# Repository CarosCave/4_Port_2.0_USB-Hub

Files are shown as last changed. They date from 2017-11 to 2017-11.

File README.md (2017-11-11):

# 4_Port_2.0_USB-Hub
I made a 4 port 2.0 USB-Hub with an exar XR22404 Chip. I wanted to test the schematic for the USB-Chip to use it in a further project. Version 1 is up and running here. But the costs for one complete equipped PCB is about 60€. Now in V2.0 I decreased the costs to 28€ for the parts.

You will find the:
-  CAD-Files in the folder **KiCAD**
-  The manufacturing files in the folder **Gerber-files**
-  The PDF documents in the folder **PDF**
-  The licence files from CERN OHL v. 1.2 under **Licence**

Or you order the complete Project by my friends from Aisler B.V.. The will deliver the complete project incl. all parts (excl. the USB-Chip from Exar). You'll find the project under the following link:
https://aisler.net/DK1CMB/4-port-2-0-usb-hub/main-pcb

The USB-Chip is an Exar XR22404CG28TR-F.

## Licence:  
**Copyright Caroline Brix 2017.**  
This documentation describes Open Hardware and is licensed under the CERN OHL v. 1.2.
You may redistribute and modify this documentation under the terms of the CERN OHL v.1.2. (http://ohwr.org/cernohl). This documentation is distributed WITHOUT ANY EXPRESS OR IMPLIED WARRANTY, INCLUDING OF MERCHANTABILITY, SATISFACTORY QUALITY AND FITNESS FOR A PARTICULAR PURPOSE. Please see the CERN OHL v.1.2 for applicable conditions

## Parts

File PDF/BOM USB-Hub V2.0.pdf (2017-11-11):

ID | Bezeichner | Gehäuse | Stückzahl | Bezeichnung | Hersteller | Hersteller-Teilenummer | Mouser-Bestellnummer | Digikey-Bestellnummer | Preis Mouser | Preis Digikey
| Identifier | Case | Pieces | Description | Manufacturer | Manufacturer part number | Mouser part number | Digikey part number | Costs Mouser | Costs Digikey
1 | IC1 | SSOP-28 | 1 | USB-IC USB 2.0 4-Port Hub | Exar | XR22404CG28TR-F | 701-XR22404CG28TR-F | nA | 2,02 € | 2,02 € | | - €
2 | J1 | USB B | 1 | USB_B_WE | Wurth | 61400416121 | 710-61400416121 | 732-2108-ND | 1,20 € | 1,20 € | 1,20 € | 1,20 €
3 | J6,J7,J8,J9 | USB A | 4 | USB_A_shielded | Wurth | 614004160211 | 710-614004160211 | 732-8248-ND | 1,50 € | 6,00 € | 1,48 € | 5,92 €
4 | C1,C3,C5 | SMD 0805 | 3 | 100nF | Wurth | 885012207072 | 710-885012207072 | 732-8061-1-ND | 0,06 € | 0,18 € | 0,09 € | 0,27 €
5 | C2,C4 | SMD 0805 | 2 | 4,7µF | Vishay | VJ0805G475KXYTW1BC | 77-VJ0805G475KXYTBC | - | 0,09 € | 0,17 € | | - €
| | | | | Taiyo | TMK212BJ475KG-T | - | 587-1782-1-ND | | | 0,24 € | 0,48 €
6 | C6,C7,C8,C9,C10,C11,C12,C13 | SMD 0805 | 8 | 680nF | Kemet | C0805C684K4RACTU | 80-C0805C684K4R | 399-9267-1-ND | 0,17 € | 1,36 € | 0,17 € | 1,36 €
7 | F1 | SMD 1206 | 1 | Polyfuse | Eaton | PTS120615V050 | 504-PTS120615V050 | 283-3140-1-ND | 0,26 € | 0,26 € | 0,27 € | 0,27 €
8 | FL1,FL2,FL3,FL4,FL5 | 1206 | 5 | EMI Common Mode Filter | Wurth | 744232090 | 710-744232090 | 732-1469-1-ND | 1,12 € | 5,60 € | 1,12 € | 5,60 €
9 | L1,L2,L3,L4 | SMD 0805 | 4 | 600R@100MHz | Wurth | 74279204 | 710-74279204 | 732-1620-1-ND | 0,19 € | 0,76 € | 0,20 € | 0,80 €
10 | R1,R2,R10 | SMD 0805 | 3 | 2k7 | Vishay | CRCW08052K70JNEA | 71-CRCW08052K70JNEA | 541-2.7KACT-ND | 0,09 € | 0,26 € | 0,08 € | 0,24 €
11 | R3 | SMD 0805 | 1 | 470 | Panasonic | ERJ-U06F4700V | 667-ERJ-U06F4700V | - | 0,23 € | 0,23 € | | - €
| | | | | Bourns | CR0805-FX-4700ELF | - | CR0805-FX-4700ELFCT-ND | | | 0,08 € | 0,08 €
12 | R4 | SMD 0805 | 1 | 40k2 | Vishay | CRCW080540K2FKEA | 71-CRCW0805-40.2K-E3 | 541-40.2KCCT-ND | 0,09 € | 0,09 € | 0,08 € | 0,08 €
13 | R5,R8,R9 | SMD 0805 | 3 | 10k | Yageo | RC0805FR-0710KL | 603-RC0805FR-0710KL | 311-10.0KCRCT-ND | 0,09 € | 0,26 € | 0,08 € | 0,24 €
14 | R6 | SMD 0805 | 1 | 0 | Yageo | RC0805JR-070RL | 603-RC0805JR-070RL | 311-0.0ARCT-ND | 0,09 € | 0,09 € | 0,08 € | 0,08 €
15 | R7 | SMD 0805 | 1 | 100k | Yageo | RC0805FR-07100KL | 603-RC0805FR-07100KL | 311-100KCRCT-ND | 0,09 € | 0,09 € | 0,08 € | 0,08 €
16 | U1,U2,U3,U4,U5 | SOT-23-6L | 5 | WE-TVS Diode | Wurth | 82400102 | 710-82400102 | 732-4473-1-ND | 0,74 € | 3,70 € | 0,74 € | 3,70 €
17 | Y1 | SMD 3225 | 1 | 12MHz | Diodes Incorporated | FL1200135 | 729-FL1200135 | FL1200135 CT-ND | 0,72 € | 0,72 € | 0,59 € | 0,59 €
18 | D1,D2,D3,D4,D5 | SMD 0805 | 5 | LED | Kingbright | APT2012SGC | 604-APT2012SGC | 754-1131-1-ND | 0,07 € | 0,36 € | 0,33 € | 1,65 €
19 | Q1 | SOT-23 | 1 | MOSFET T1 60V PCH | ON Semiconductor | NVR5124PLT1G | 863-NVR5124PLT1G | - | 0,37 € | 0,37 € | | - €
| | | | MOSFET P-CH 60V 1.8A CPH3 | ON Semiconductor | CPH3351-TL-W | - | CPH3351-TL-WOSCT-ND | | - € | 0,41 € | - €
20 | J2,J3,J4,J5 | 3.2mm | 4 | Mounting Hole
| | | | | | | | | Netto | 23,69 € | | 22,64 €
| | | | | | | | | Brutto | 28,19 € | | 26,94 €

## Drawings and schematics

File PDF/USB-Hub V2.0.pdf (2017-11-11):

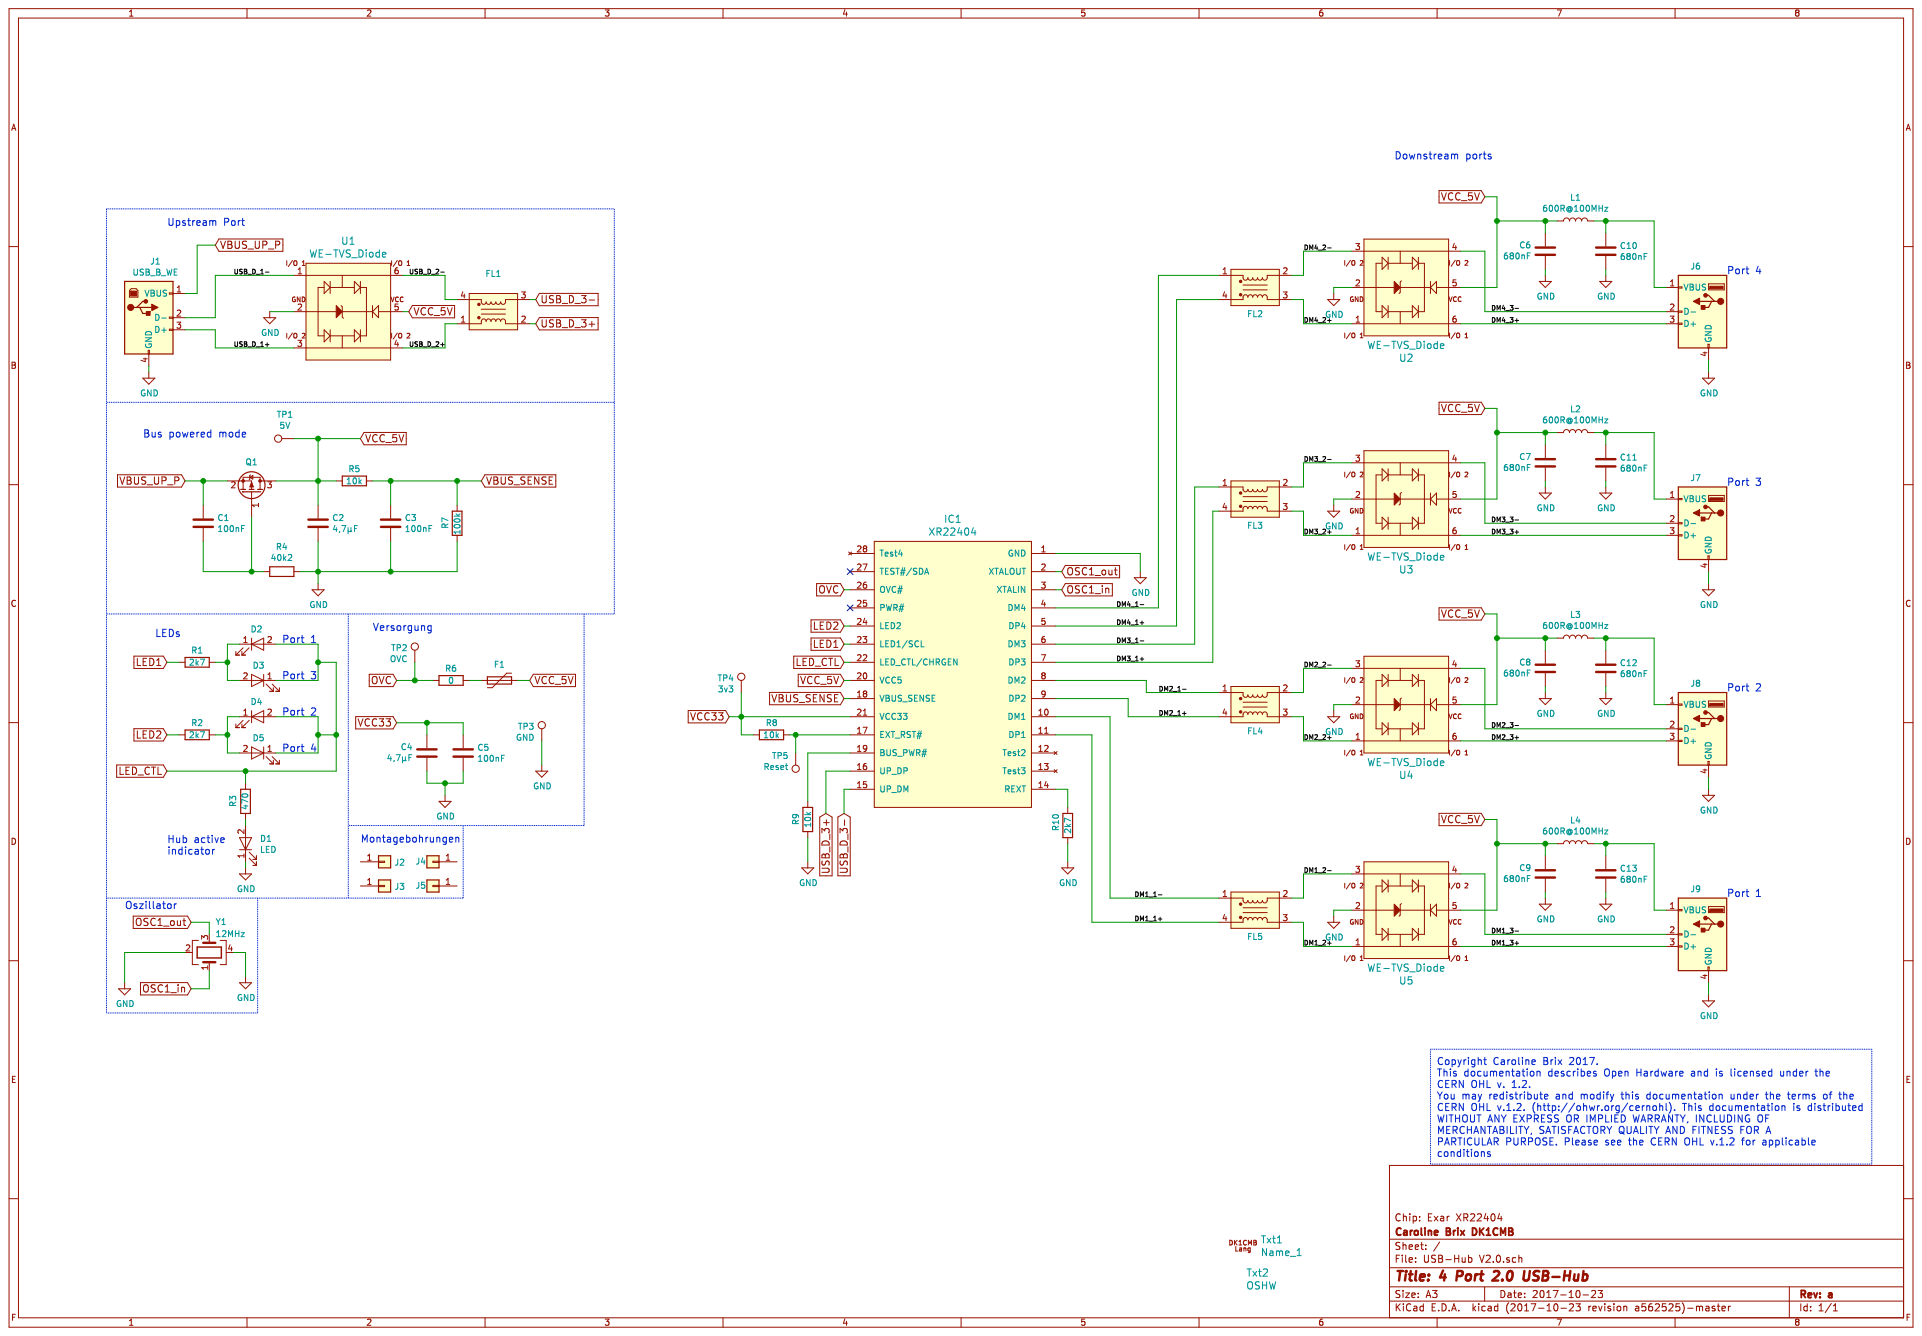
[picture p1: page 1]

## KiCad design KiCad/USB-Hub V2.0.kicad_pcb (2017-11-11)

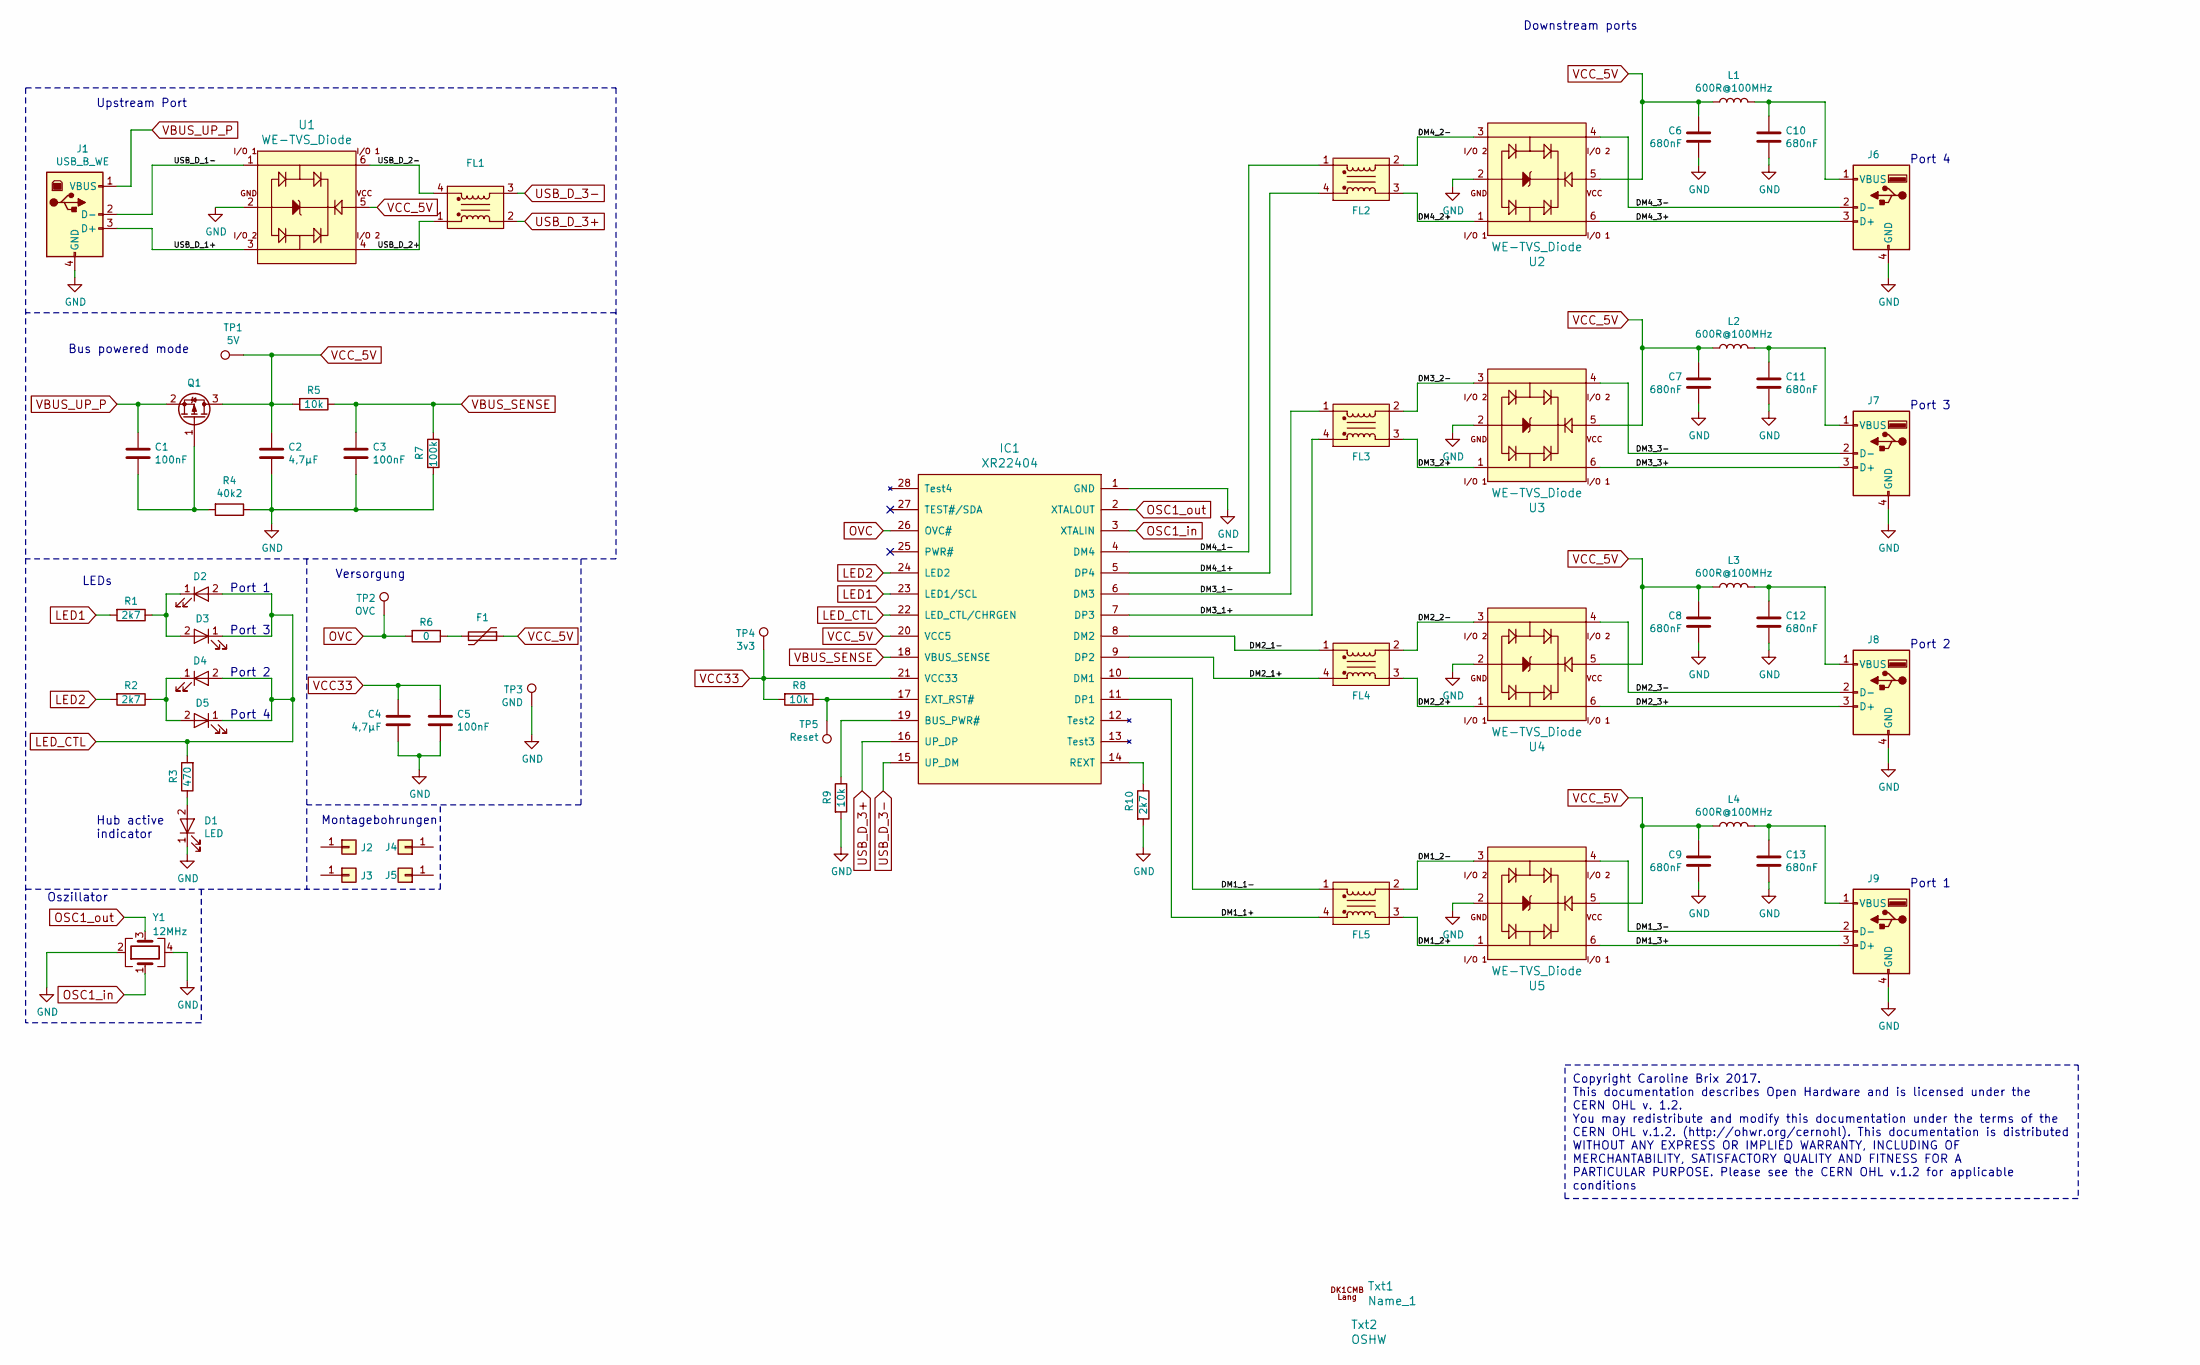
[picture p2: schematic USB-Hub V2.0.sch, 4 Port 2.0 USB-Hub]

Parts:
C1, C3, C5: 100nF; R_0805_HandSoldering
C2, C4: 4,7µF; R_0805_HandSoldering
C6, C7, C8, C9, C10, C11, C12, C13: 680nF; R_0805_HandSoldering
D1, D2, D3, D4, D5: LED; LED_0805_HandSoldering
F1: Polyfuse; R_1206_HandSoldering
FL1, FL2, FL3, FL4, FL5: EMI_Common_Mode_Line_Filter; WE-CNSW
IC1: XR22404
J1: USB_B_WE; USB_B_THT_WE
J2, J3, J4, J5: Conn_01x01; MountingHole_3.2mm_M3_Pad
J6, J7, J8, J9: USB_A_shielded; USB_A_shielded_WE
L1, L2, L3, L4: 600R@100MHz; R_0805_HandSoldering
Q1: NTR2101P; SOT-23
R1, R2, R10: 2k7; R_0805_HandSoldering
R3: 470; R_0805_HandSoldering
R4: 40k2; R_0805_HandSoldering
R5, R8, R9: 10k; R_0805_HandSoldering
R6: 0; R_0805_HandSoldering
R7: 100k; R_0805_HandSoldering
TP1: 5V; Test_Point_Pad_d3.0mm
TP2: OVC; Test_Point_Pad_d3.0mm
TP3: GND; Test_Point_Pad_d3.0mm
TP4: 3v3; Test_Point_Pad_d3.0mm
TP5: Reset; Test_Point_Pad_d3.0mm
Txt1: Name_1; Name_Lang
Txt2: OSHW; OSHW-Logo2_7.3x6mm_SilkScreen
U1, U2, U3, U4, U5: WE-TVS_Diode; SOT23-6L
Y1: 12MHz; Crystal_SMD_3225-4pin_3.2x2.5mm_HandSoldering

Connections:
/DM1_1+: FL5.4, IC1.11 (DP1)
/DM1_1-: FL5.1, IC1.10 (DM1)
/DM1_2+: FL5.3, U5.1
/DM1_2-: FL5.2, U5.3
/DM1_3+: J9.3 (D+), U5.6
/DM1_3-: J9.2 (D-), U5.4
/DM2_1+: FL4.4, IC1.9 (DP2)
/DM2_1-: FL4.1, IC1.8 (DM2)
/DM2_2+: FL4.3, U4.1
/DM2_2-: FL4.2, U4.3
/DM2_3+: J8.3 (D+), U4.6
/DM2_3-: J8.2 (D-), U4.4
/DM3_1+: FL3.4, IC1.7 (DP3)
/DM3_1-: FL3.1, IC1.6 (DM3)
/DM3_2+: FL3.3, U3.1
/DM3_2-: FL3.2, U3.3
/DM3_3+: J7.3 (D+), U3.6
/DM3_3-: J7.2 (D-), U3.4
/DM4_1+: FL2.4, IC1.5 (DP4)
/DM4_1-: FL2.1, IC1.4 (DM4)
/DM4_2+: FL2.3, U2.1
/DM4_2-: FL2.2, U2.3
/DM4_3+: J6.3 (D+), U2.6
/DM4_3-: J6.2 (D-), U2.4
/USB_D_1+: J1.3 (D+), U1.3
/USB_D_1-: J1.2 (D-), U1.1
/USB_D_2+: FL1.1, U1.4
/USB_D_2-: FL1.4, U1.6
GND: C2.2, C3.2, C4.1, C5.2, C6.1, C7.1, C8.1, C9.1, C10.2, C11.2, C12.2, C13.2, D1.1 (K), IC1.1 (GND), J1.4 (GND), J6.4 (GND), J7.4 (GND), J8.4 (GND), J9.4 (GND), R4.1, R7.2, R9.2, R10.2, TP3.1, U1.2, U2.2, U3.2, U4.2, U5.2, Y1.2, Y1.4
LED1: IC1.23 (LED1/SCL), R1.2
LED2: IC1.24 (LED2), R2.2
LED_CTL: D2.2 (A), D3.1 (K), D4.2 (A), D5.1 (K), IC1.22 (LED_CTL/CHRGEN), R3.2
unnamed: C1.2, Q1.1 (G), R4.2
unnamed: C10.1, J6.1 (VBUS), L1.2
unnamed: C11.1, J7.1 (VBUS), L2.2
unnamed: C12.1, J8.1 (VBUS), L3.2
unnamed: C13.1, J9.1 (VBUS), L4.2
unnamed: D1.2 (A), R3.1
unnamed: D2.1 (K), D3.2 (A), R1.1
unnamed: D4.1 (K), D5.2 (A), R2.1
unnamed: F1.2, R6.1
unnamed: IC1.14 (REXT), R10.1
unnamed: IC1.17 (EXT_RST#), R8.1, TP5.1
unnamed: IC1.19 (BUS_PWR#), R9.1
OSC1_in: IC1.3 (XTALIN), Y1.1
OSC1_out: IC1.2 (XTALOUT), Y1.3
OVC: IC1.26 (OVC#), R6.2, TP2.1
USB_D_3+: FL1.2, IC1.16 (UP_DP)
USB_D_3-: FL1.3, IC1.15 (UP_DM)
VBUS_SENSE: C3.1, IC1.18 (VBUS_SENSE), R5.1, R7.1
VBUS_UP_P: C1.1, J1.1 (VBUS), Q1.2 (S)
VCC33: C4.2, C5.1, IC1.21 (VCC33), R8.2, TP4.1
VCC_5V: C2.1, C6.2, C7.2, C8.2, C9.2, F1.1, IC1.20 (VCC5), L1.1, L2.1, L3.1, L4.1, Q1.3 (D), R5.2, TP1.1, U1.5, U2.5, U3.5, U4.5, U5.5

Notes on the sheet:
Bus powered mode
Port 1
Port 3
Port 2
Port 4
LEDs
Hub active indicator
Oszillator
Versorgung
Downstream ports
Port 3
Montagebohrungen
Upstream Port
Copyright Caroline Brix 2017. This documentation describes Open Hardware and is licensed under the CERN OHL v. 1.2. You may redistribute and modify this documentation under the terms of the CERN OHL v.1.2. (http://ohwr.org/cernohl). This documentation is distributed WITHOUT ANY EXPRESS OR IMPLIED W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

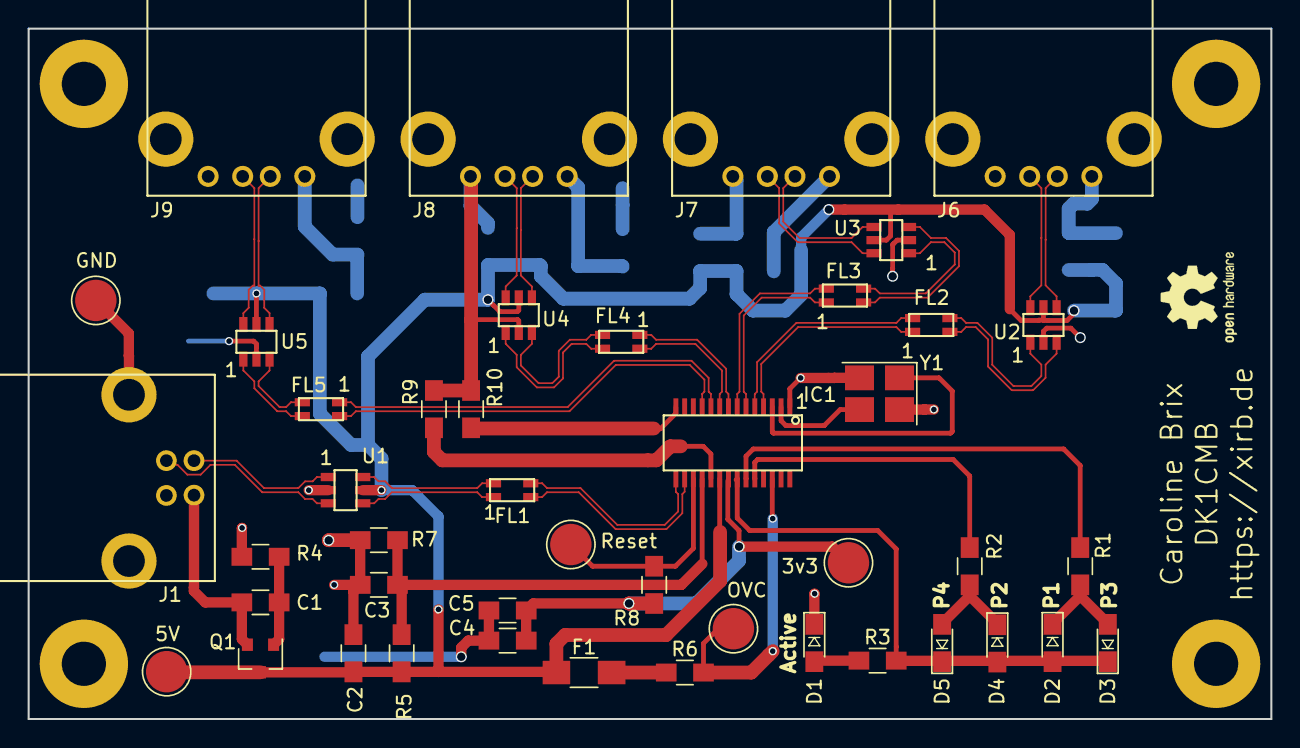
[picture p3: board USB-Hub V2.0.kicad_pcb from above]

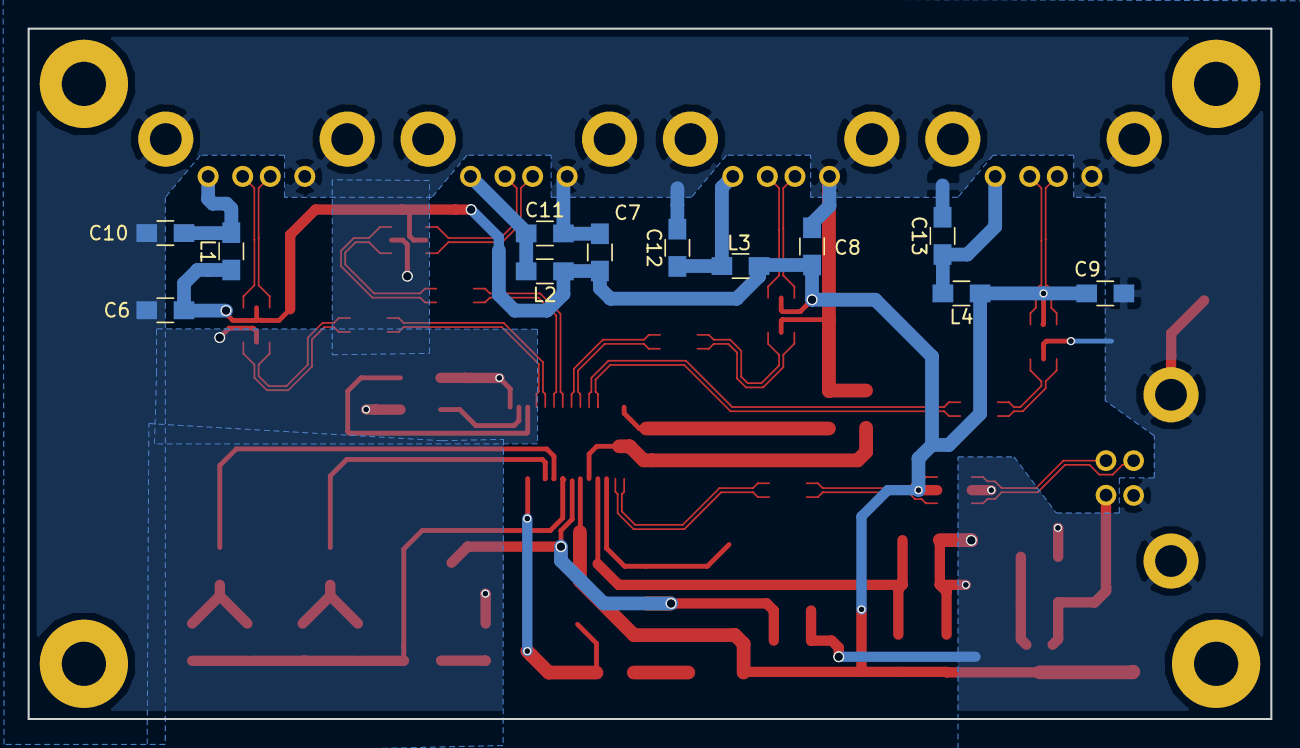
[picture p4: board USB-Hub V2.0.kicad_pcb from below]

Board: 2 copper layers, 90.0 x 50.0 mm, 62 parts (12 on the bottom side), 53 nets.
